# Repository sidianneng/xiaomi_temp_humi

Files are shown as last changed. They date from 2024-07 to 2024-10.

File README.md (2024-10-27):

# 探索版小米温湿度计
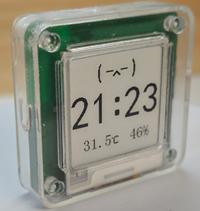
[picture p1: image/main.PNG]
xiaomi_temp_humi


## 1 项目概述
本项目基于小米温湿度计2代进行，在吸收了3代和pro版本的优势后，整合为一个探索版本。

## 2 系统框图
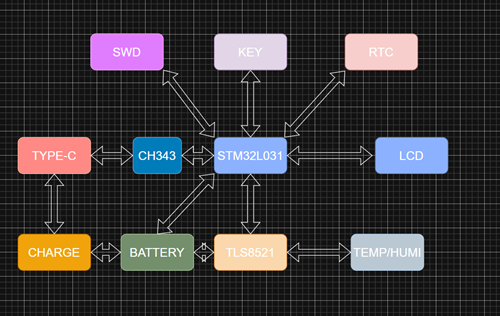
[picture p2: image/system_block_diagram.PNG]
system_block_diagram


## 3 功能介绍
### 3.1 基础功能
* 基础功能与官方小米温湿度计2代完全一致
### 3.2 新增功能
* 添加了3代中的实现显示与按键控制
* 添加了pro版本中的墨水屏功能

## 4 原理解析
在官方的原始设计中，设备的主控为TLS8251,屏幕驱动为一颗定制芯片，屏幕驱动与TLS8251之间通过I2C通信。在我的新设计中，使用STM32L031代替屏幕驱动芯片。在其固件中兼容了原有的显示驱动，同时实现了墨水屏，按键，时钟的驱动。

## 5 工程目录结构
* 3d-model:结构件3D打印使用的STL文件
* hardware:原理图，PCB位号图，PCB生产使用的gerber文件，以及物料列表和系统框图(查看工具https://app.diagrams.net/)
* image:工程使用的各种图片文件
* source_code:STM32L031的固件源文件，另外在工程的release中存放了最新发布的固件
* tools:用来进行时间同步的html源码，通过浏览器打开即可使用

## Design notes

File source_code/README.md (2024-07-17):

## preparation of compile
```
apt install gcc-arm-none-eabi
```

## compile image
```
make
```

## where is the image
```
ls ./build/*.hex
```

## download the image
```
./tools/download.sh
```

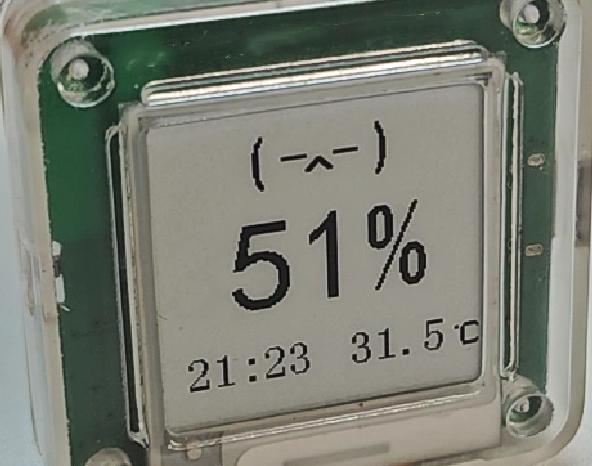
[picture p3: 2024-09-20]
image/display2.PNG

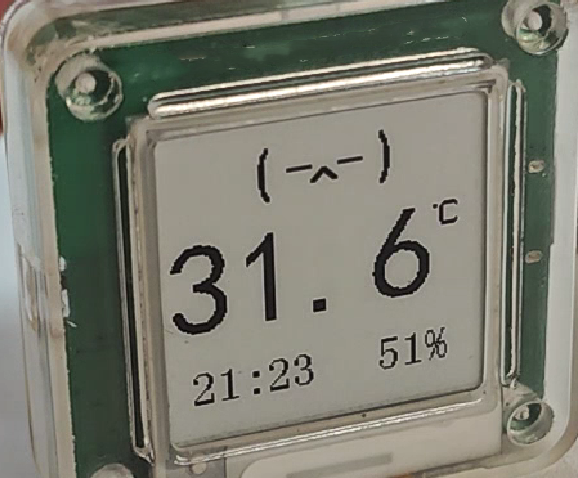
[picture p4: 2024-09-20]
image/display1.PNG

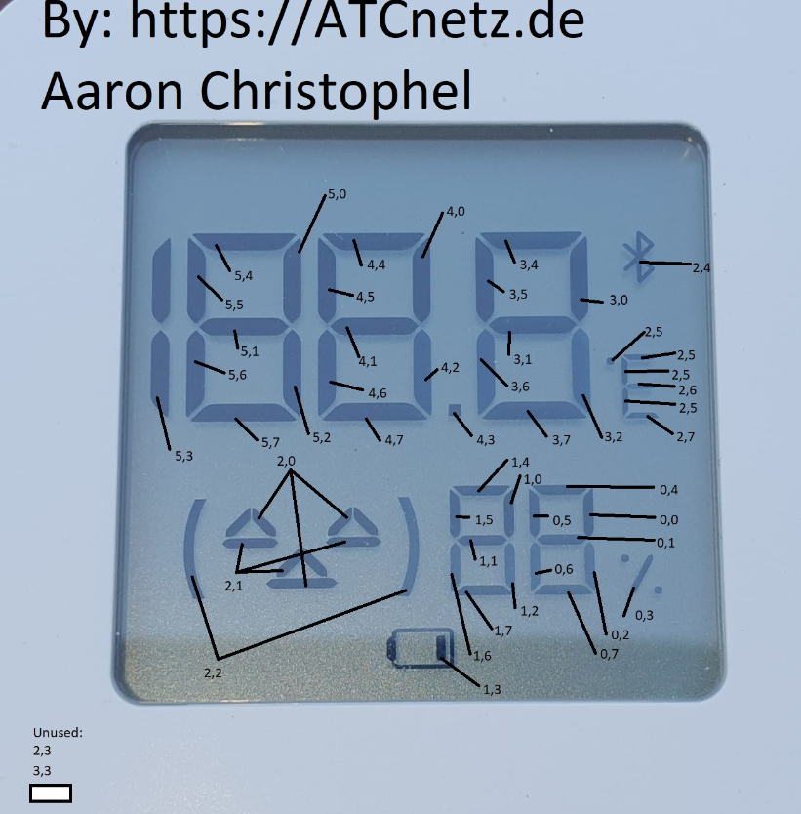
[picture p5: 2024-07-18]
image/digital-tube.png

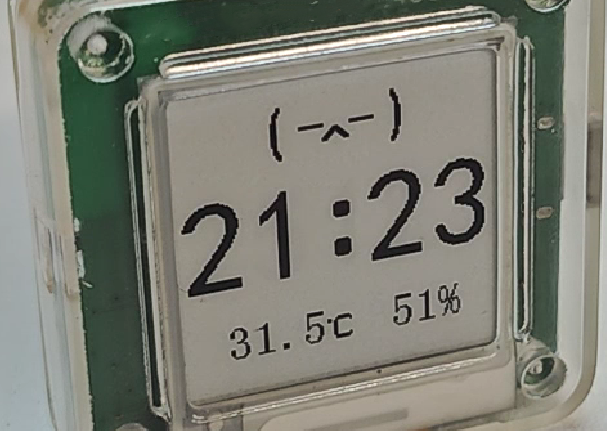
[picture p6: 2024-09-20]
image/display3.PNG

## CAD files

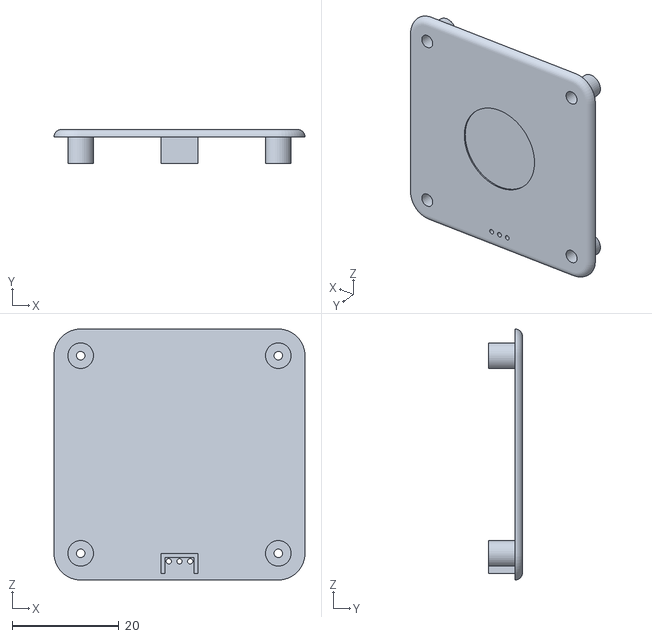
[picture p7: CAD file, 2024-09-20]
3d-model/xiaomi_temp_humi_back_cover_v11.stl
47.0 x 6.40 x 47.0

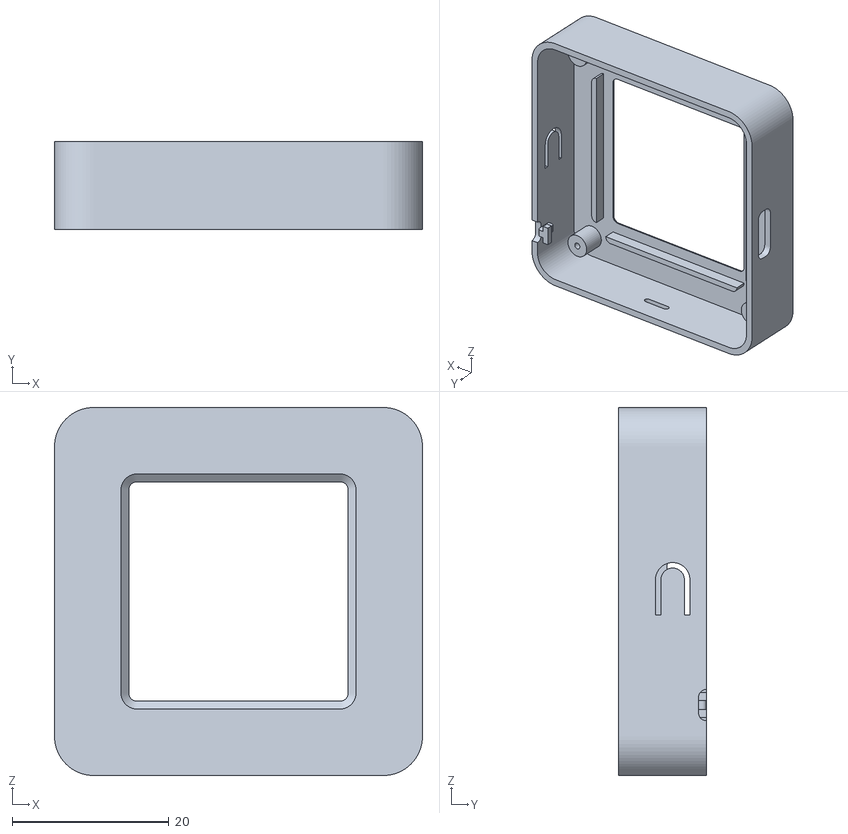
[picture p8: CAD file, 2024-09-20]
3d-model/xiaomi_temp_humi_v41.stl
47.0 x 11.2 x 47.0

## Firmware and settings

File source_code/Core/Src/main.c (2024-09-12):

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
/* Includes ------------------------------------------------------------------*/
#include "main.h"
#include "i2c.h"
#include "usart.h"
#include "gpio.h"
#include "log.h"
#include "EPD_GUI.h"
#include "Pic.h"
#include "i2c_slave.h"


/* USER CODE BEGIN PV */
uint8_t ImageBW[2888];

struct I2c_Slave_Pack i2c_slave_pack;
struct Lcd_Data_Pack lcd_data_pack;

uint32_t last_key_cnt = 0;
extern uint32_t key_cnt;

extern uint8_t uart_data[], uart_data_ready;

static LL_RTC_TimeTypeDef RTC_TimeStruct = {0};
static LL_RTC_DateTypeDef RTC_DateStruct = {0};
/* USER CODE END PV */

void SystemClock_Config(void);
/**
  * @brief  The application entry point.
  * @retval int
  */
int main(void)
{
  /* MCU Configuration--------------------------------------------------------*/

  /* Reset of all peripherals, Initializes the Flash interface and the Systick. */

  LL_APB2_GRP1_EnableClock(LL_APB2_GRP1_PERIPH_SYSCFG);
  LL_APB1_GRP1_EnableClock(LL_APB1_GRP1_PERIPH_PWR);

  /* System interrupt init*/

  /* Configure the system clock */
  SystemClock_Config();

  /* USER CODE BEGIN SysInit */
  LL_RCC_SetClkAfterWakeFromStop(LL_RCC_STOP_WAKEUPCLOCK_HSI);
  /* USER CODE END SysInit */

  /* Initialize all configured peripherals */
  MX_GPIO_Init();
  MX_I2C1_Init();
  MX_USART2_UART_Init();
  MX_RTC_Init();
  Log_Init();
  Log_Printf("xiaomi temp humi start\n");
  Log_Printf("version: %d.%d\n", MAIN_VERSION, SUB_VERSION);
  Paint_NewImage(ImageBW,EPD_W,EPD_H,0,WHITE);
  Paint_Clear(WHITE);
  Log_Printf("lcd init ok\n");
  EPD_FastMode1Init();
  EPD_Display_Clear();
  EPD_FastUpdate();
  EPD_Clear_R26H();
 
  uint8_t time_hour, time_min;
  uint8_t last_time_hour, last_time_min;
  float temp;
  float last_temp;
  int8_t humi;
  int8_t last_humi;
  uint32_t rev_id = 0;
  //bit0:i2c receive data
  //bit1:rtc time change 
  //bit2:key input
  uint8_t lcd_update_flag = 0x80;

  //LL_GPIO_ResetOutputPin(GPIOB, LL_GPIO_PIN_1);
  //LL_mDelay(50);
  //LL_GPIO_SetOutputPin(GPIOB, LL_GPIO_PIN_1);
  /* USER CODE BEGIN 2 */
  Log_Printf("rev:0x%x\n", LL_DBGMCU_GetRevisionID());
  /* USER CODE END 2 */

  /* Infinite loop */
  /* USER CODE BEGIN WHILE */
  while (1)
  {
    /* USER CODE END WHILE */

    /* USER CODE BEGIN 3 */
    //LL_mDelay(1000);
    Log_Printf("loop test %d\n", key_cnt);
    //Log_Printf("enter sleep\n");
    LL_EXTI_EnableIT_0_31(LL_EXTI_LINE_14);
    LL_EXTI_EnableIT_0_31(LL_EXTI_LINE_9);
    PrepareUSARTToStopMode();
    EnterSleepMode();
    //Log_Printf("wakeup from sleep\n");
    if(i2c_slave_pack.raw_data_len) {
            i2c_slave_pack.raw_data_len = 0;
            Update_Lcd_Data(&i2c_slave_pack, &lcd_data_pack);
            Log_Printf("temp:%d\n", (uint16_t)(lcd_data_pack.temp*10));
            Log_Printf("humi:%d\n", lcd_data_pack.humi);
            Log_Printf("smile:%d\n", lcd_data_pack.smile);
            Log_Printf("ble:%d\n", lcd_data_pack.ble);
            Log_Printf("format:%d\n", lcd_data_pack.temp_format);
            Log_Printf("battery:%d\n", lcd_data_pack.battery);
            if(lcd_data_pack.ble)
                EPD_ShowPicture(120, 14, 24, 24, gImage_2424_bt, BLACK);
	    else
                EPD_ShowPicture(120, 14, 24, 24, gImage_2424_nobt, BLACK);
            if(lcd_data_pack.smile == 1)
        	EPD_ShowPicture(44, 10, 64, 32, gImage_6432_smile_happy, BLACK);
            else if(lcd_data_pack.smile == 2)
        	EPD_ShowPicture(44, 10, 64, 32, gImage_6432_smile_sad, BLACK);
	    if(lcd_data_pack.battery)
		EPD_ShowPicture(10, 14, 24, 24, gImage_2424_bat, BLACK);
	    else
		EPD_ShowPicture(10, 14, 24, 24, gImage_2424_nobat, BLACK);
            temp = lcd_data_pack.temp;
            humi = lcd_data_pack.humi;
	    lcd_update_flag |= (0x01 << 0);
    }

    time_hour = __LL_RTC_CONVERT_BCD2BIN(LL_RTC_TIME_GetHour(RTC));
    time_min  = __LL_RTC_CONVERT_BCD2BIN(LL_RTC_TIME_GetMinute(RTC));
    if(time_hour != last_time_hour || time_min != last_time_min)
	    lcd_update_flag |= (0x01 << 1);
    last_time_hour = time_hour;
    last_time_min  = time_min;

    if(last_key_cnt != key_cnt%3 || (lcd_update_flag & 0x01)) {
	memset(ImageBW, 0xff, 152 * 152 / 8 - 152 * 5);
    	if(key_cnt%3 == 0) {
                EPD_ShowNum(0, 44, time_hour, 2, 64, BLACK);
                EPD_ShowPicture(64, 44, 24, 64, gImage_2464_colon, BLACK);
                EPD_ShowNum(88, 44, time_min, 2, 64, BLACK);
                EPD_ShowFloatNum1(20, 114, temp, 3, 1, 24, BLACK);
                EPD_ShowPicture(68, 114, 12, 24, gImage_1224_c, BLACK);
                EPD_ShowNum(100 ,114, humi, 2, 24, BLACK);
        	EPD_ShowChar(124, 114, '%', 24, BLACK);
    	} else if(key_cnt%3 == 1) {
                EPD_ShowFloatNum1(0 ,44, temp, 3, 1, 64, BLACK);
                EPD_ShowPicture(128, 44, 12, 24, gImage_1224_c, BLACK);
                EPD_ShowNum(10, 114, time_hour, 2, 24, BLACK);
        	EPD_ShowChar(34, 114, ':', 24, BLACK);
                EPD_ShowNum(46, 114, time_min, 2, 24, BLACK);
                EPD_ShowNum(100, 114, humi, 2, 24, BLACK);
        	EPD_ShowChar(124, 114, '%', 24, BLACK);
    	} else {
                EPD_ShowNum(32, 44, humi, 2, 64, BLACK);
        	EPD_ShowChar(96, 44, '%', 64, BLACK);
                EPD_ShowNum(10, 114, time_hour, 2, 24, BLACK);
        	EPD_ShowChar(34, 114, ':', 24, BLACK);
                EPD_ShowNum(46, 114, time_min, 2, 24, BLACK);
                EPD_ShowFloatNum1(88, 114, temp, 3, 1, 24, BLACK);
                EPD_ShowPicture(140, 114, 12, 24, gImage_1224_c, BLACK);
    	}
	lcd_update_flag |= (0x01 << 2);
    }
    last_key_cnt = key_cnt%3;

    if(uart_data_ready) {
            Log_Printf("u:%s\n", uart_data);
            RTC_TimeStruct.Hours =   (uart_data[8] - 0x30) * 0x10 + (uart_data[9] - 0x30);
            RTC_TimeStruct.Minutes = (uart_data[10] - 0x30) * 0x10 + (uart_data[11] - 0x30);
            RTC_TimeStruct.Seconds = (uart_data[12] - 0x30) * 0x10 + (uart_data[13] - 0x30);
            LL_RTC_TIME_Init(RTC, LL_RTC_FORMAT_BCD, &RTC_TimeStruct);
            RTC_DateStruct.Month = (uart_data[4] - 0x30) * 0x10 + (uart_data[5] - 0x30);
            RTC_DateStruct.Day = (uart_data[6] - 0x30) * 0x10 + (uart_data[7] - 0x30);
            RTC_DateStruct.Year =(uart_data[2] - 0x30) * 0x10 + (uart_data[3] - 0x30) ;
            LL_RTC_DATE_Init(RTC, LL_RTC_FORMAT_BCD, &RTC_DateStruct);
            uart_data_ready = 0;
    }

    if(lcd_update_flag) {
        EPD_Display(ImageBW);
        EPD_PartUpdate();
    }

    lcd_update_flag = 0x00;

    //Log_Printf("rtc year:%d\n", __LL_RTC_CONVERT_BCD2BIN(LL_RTC_DATE_GetYear(RTC)));
    //Log_Printf("rtc month:%d\n", __LL_RTC_CONVERT_BCD2BIN(LL_RTC_DATE_GetMonth(RTC)));
    //Log_Printf("rtc weekday:%d\n", __LL_RTC_CONVERT_BCD2BIN(LL_RTC_DATE_GetWeekDay(RTC)));
    //Log_Printf("rtc hour:%d\n", __LL_RTC_CONVERT_BCD2BIN(LL_RTC_TIME_GetHour(RTC)));
    //Log_Printf("rtc min:%d\n", __LL_RTC_CONVERT_BCD2BIN(LL_RTC_TIME_GetMinute(RTC)));
    //Log_Printf("rtc sec:%d\n", __LL_RTC_CONVERT_BCD2BIN(LL_RTC_TIME_GetSecond(RTC)));
  }
  /* USER CODE END 3 */
}

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
/* USER CODE BEGIN 4 */
void EnterSleepMode(void)
{
  LL_PWR_ClearFlag_WU();
  LL_PWR_SetRegulModeLP(LL_PWR_REGU_LPMODES_LOW_POWER);
  /* Set Stop 0 mode when CPU enters deepsleep */
  LL_PWR_SetPowerMode(LL_PWR_MODE_STOP);

  /* Set SLEEPDEEP bit of Cortex System Control Register */
  LL_LPM_EnableDeepSleep();

  /* Request Wait For Interrupt */
  __WFI();
}
/* USER CODE END 4 */
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


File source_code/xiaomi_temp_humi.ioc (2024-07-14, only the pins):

Mcu.UserName=STM32L031F6Px
PA0-CK_IN.Signal=GPIO_Output
PA1.Signal=GPIO_Output
PA10.Signal=I2C1_SDA
PA2.Signal=USART2_TX
PA3.Signal=USART2_RX
PA4.Signal=GPIO_Output
PA5.Signal=GPIO_Output
PA6.Signal=GPIO_Output
PA7.Signal=GPIO_Input
PA9.Signal=I2C1_SCL

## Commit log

2024-06-29 led blink demo ok
2024-06-29 uart is ok
2024-06-29 printf is ok
2024-07-09 change the gpio of uart2 to fix swd download issue Cause the SWCLK and uart tx share the same pin(PA14).
    [main.c]
2024-07-10 add basic driver for lcd
2024-07-14 change MCU to STM32L031F6 due to the lack of RAM
2024-07-15 lcd driver is ok
2024-07-16 enable i2c slave mode
2024-07-17 i2c slave can be detected by cmd i2cdetect pi@raspberrypi:~ $ i2cdetect -y -r 1 0 1 2 3 4 5 6 7 8 9 a b c d e f 00: -- -- -- -- -- -- -- -- 10: -- -- -- 13 -- -- -- -- -- -- -- -- -- -- -- -- 20: -- 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
2024-07-17 i2c slave can receive data now
2024-07-18 upload the digital tube image for LCD debug Thanks for the job from Aaron Christophel.
2024-07-18 i2c slave can receive more data
2024-07-20 i2c slave detect the stop flag
2024-07-20 add i2c slave data parse for lcd display
2024-07-20 add implementation of i2c slave data parse for display
2024-07-20 add demo code to test i2c slave display data parse
2024-07-21 update i2c slave addr for B1.7 hardware
2024-07-21 i2c slave data parse is ok refernece link: https://github.com/atc1441/ATC_MiThermometer/blob/df42fe56ea1ad38700478f3f3a73d0937c490e50/ATC_Thermometer/lcd.c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
2024-08-17 LCD can display data from i2c master
2024-08-17 uart receive data ok
2024-08-17 update uart buffer size
2024-08-31 add battery icon
2024-09-01 system can wake up from gpio interrupt now
2024-09-02 i2c wake up from stop mode init commit
2024-09-03 commment out useless code for i2c slave wakeup debug from stop mode
2024-09-03 i2c slave address match wakeup stop mode is ok
2024-09-04 fix i2c wakeup
2024-09-04 fix the i2c master read command block problem Just like `i2cdetect -y -r 1`
2024-09-05 Get REV_ID for mcu According to the errata of stm32l031xx. Some REV_ID(0x1000,0x2000,0x2008) of stm32l031 can't wakeup system from stop mode. We use this to check the mcu rev id. Reference link: http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
    [main.c]
2024-09-05 Due to the unknow issue of joint debug with shtv3 sensor. I gived up the i2c addr match wakeup and use the SCLK gpio wakeup
    [i2c.c]
2024-09-10 change the system clock to HSI Cause both I2C and usart can wakeup stop mode when their clock is from HSI.
2024-09-11 remove raw data display of i2c slave
2024-09-11 fix the key input
    [main.c]
2024-09-11 clean up the display before switch different layout
2024-09-12 add display of battery icon
2024-09-12 speed up system init time to receive the first i2c package from i2c master
2024-09-20 upload the schematic pcb bom and gerber files
2024-09-20 upload the 3d model design files
    [xiaomi_temp_humi_back_cover_v11.stl, xiaomi_temp_humi_v41.stl]

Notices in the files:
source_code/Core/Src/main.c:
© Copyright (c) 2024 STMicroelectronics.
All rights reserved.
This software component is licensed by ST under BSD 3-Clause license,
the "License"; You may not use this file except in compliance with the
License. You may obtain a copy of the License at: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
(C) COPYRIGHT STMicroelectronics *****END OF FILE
